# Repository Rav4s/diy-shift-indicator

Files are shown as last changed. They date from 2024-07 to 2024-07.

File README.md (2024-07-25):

# K-Line (ISO9141) Shift Indicator
A DIY shift indicator for manual transmission cars like my Mazda MX-5 with a K-Line (ISO9141) OBDII interface. The device uses a series of LEDs that illuminate based on engine speed (RPM) to help the driver know when to shift gears in high-pressure situations. My technical writeup for this project, which includes rationale, insight into my design/development process, and future plans can be found [here](https://drive.google.com/file/d/1h4sEP5iF2pkmRt12-wAFUMqSv9QvsOz3/view). Additionally, here are videos of the [startup sequence](https://drive.google.com/file/d/1yGfBQFOaLi5DHMowFaSR_DUKHt-pPL1-/view?usp=sharing) and the [device in action](https://drive.google.com/file/d/1uUzjxnDBYHzpRwuf0LmYo11RxKfqu849/view?usp=sharing).  

## Features
- Displays engine RPM using a set of seven LEDs
- Has three distinct LED colors to show progression from low to high RPM (green -> blue -> red)
- Begins illuminating LEDs at the lower end of shift range (3.5k) and fully illuminates by the higher end (6k), with equal steps in between
- Mounts to the dashboard without significantly obstructing the driver's view of the road
- Doesn't require any modifications to wiring/electronics of the car (plug-and-play)

## Files
The file structure of this repository is as follows: 

```
diy-shift-indicator
│   K-Line (ISO 9141) Shift Indicator Writeup.pdf -- technical writeup on design/development process and future plans
│   LICENSE
│   README.md
│
├───Code -- all Arduino code
│   ├───arduino_obd_reader_display -- code for polling and displaying RPM using LED series
│   │       arduino_obd_reader_display.ino -- handles initialization/communication over LIN bus
│   │       LED_driver.ino -- defines functions to drive and reset LEDs, provides displayRPM functionality
│   │
│   ├───LED_test -- tester sketch to ensure LED series is working
│   │       LED_test.ino
│   │
│   └───modified_iso9141_library -- modified version of the OBD9141 Arduino library used in display program
│           OBD9141.cpp
│           OBD9141.h
│
├───Debug -- Saleae logic analyzer capture files, useful for debugging initialization/connection with ECU
│       First_Success_TX_and_KLINE_Logic.sal
│       RX_Logic.sal
│       TX_and_KLINE_Logic.sal
│       TX_Logic.sal
│
└───Design -- CAD/design files from the prototyping process
    │   Device BOM.xlsx -- full bill of materials for the final product (PCB, boards, wiring, enclosure, etc.)
    │
    ├───Electronics -- breadboard, schematic, and PCB design files
    │   ├───Fritzing (Breadboard)
    │   │       Prototype Design.fzz -- breadboard setup designed for original prototype/testbed
    │   │       SN65HVDA195 IC Part.fzz -- custom Fritzing part designed for LIN transceiver IC
    │   │
    │   └───KiCad (PCB)
    │       └───Shift_Indicator_PCB
    │           │   freerouting.dsn
    │           │   Shift_Indicator_PCB.kicad_pcb -- PCB design for final product, can be exported to Gerbers for fabrication
    │           │   Shift_Indicator_PCB.kicad_pcb.zip
    │           │   Shift_Indicator_PCB.kicad_prl
    │           │   Shift_Indicator_PCB.kicad_pro
    │           │   Shift_Indicator_PCB.kicad_sch -- schematic defining all electrical connections for PCB
    │           │   Shift_Indicator_PCB.net -- netlist used to transfer schematic data to PCB design
    │           │   Shift_Indicator_PCB_BOM.csv -- bill of materials for PCB
    │
    └───Mechanics -- enclosure/lid design files
            Enclosure.3mf -- Bambu slicer file for 3D printing enclosure and lid
            Enclosure.stl -- CAD design for device enclosure, can be mounted to car dashboard 
            Lid.stl -- CAD design for lid for the enclosure
```

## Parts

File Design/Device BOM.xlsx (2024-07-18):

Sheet: Full Device BOM
Part Name | Part Number | Cost/Unit | Quantity | Total Cost
C2 (220pF Capacitor) | 0805B221K500BD | $0.04 | 1 | $0.04
C1 (100nF Capacitor) | 0805B104K101CC | $0.06 | 1 | $0.06
R3,R4,R5,R6,R7,R8,R9 (220Ω Resistor) | CRGCQ0805F220R | $0.10 | 7 | $0.70
R1 (1kΩ Resistor) | RC0805FR-071KL | $0.10 | 1 | $0.10
R2 (4.6kΩ Resistor) | ERJ-6ENF4991V | $0.11 | 1 | $0.11
D1,D2 (Rectifier Diode) | 1N4007-T | $0.17 | 2 | $0.34
J1 (11 Position Female Connector Header) | PPTC111LFBN-RC | $0.73 | 1 | $0.73
J2, J3, J4 (1 Position Male Connector Header) | PH1-01-UA | $0.10 | 3 | $0.30
F1 (Fuse Holder) | 0PTF0078P | $0.51 | 1 | $0.51
200mA Fuse | 0235.200HXP | $1.03 | 1 | $1.03
D3, D4, D5 (Green LED) | LTL-709L | $0.37 | 3 | $1.11
J13 (3 Position Female Connector Header) | PPPC031LFBN-RC | $0.38 | 1 | $0.38
D8, D9 (Red LED) | LTL-709E | $0.41 | 2 | $0.82
D6, D7 (Yellow LED) | LTL-709Y | $0.29 | 2 | $0.58
SN65HVDA195 (LIN Bus Transceiver) | SN65HVDA195QDRQ1 | $1.74 | 1 | $1.74
Arduino Uno | A000066 | $27.60 | 1 | $27.60
12V to 5V Buck Converter | B01NALDSJ0 | $9.00 | 1 | $9.00
3D Printer Filament (cost from slicer estimate) | N/A | N/A | N/A | $3.88
OBDII Wire Harness (J1962 Connector) | ‎IKG-40198 | $7.99 | 1 | $7.99

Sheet: Shift_Indicator_PCB_BOM
Reference | Value | Datasheet | Footprint | Qty | DNP | Part Number
C2 | 220pF | ~ | Capacitor_SMD:C_0805_2012Metric_Pad1.18x1.45mm_HandSolder | 1 |  | 0805B221K500BD
C1 | 100nF | ~ | Capacitor_SMD:C_0805_2012Metric_Pad1.18x1.45mm_HandSolder | 1 |  | 0805B104K101CC
R3,R4,R5,R6,R7,R8,R9 | 220Ω | ~ | Resistor_SMD:R_0805_2012Metric_Pad1.20x1.40mm_HandSolder | 7 |  | CRGCQ0805F220R
R1 | 1kΩ | ~ | Resistor_SMD:R_0805_2012Metric_Pad1.20x1.40mm_HandSolder | 1 |  | RC0805FR-071KL
R2 | 4.6kΩ | ~ | Resistor_SMD:R_0805_2012Metric_Pad1.20x1.40mm_HandSolder | 1 |  | ERJ-6ENF4991V
D1,D2 | 1N4007 | http://www.vishay.com/docs/88503/1n4001.pdf | Diode_THT:D_DO-41_SOD81_P10.16mm_Horizontal | 2 |  | 1N4007-T
J1 | Arduino Connector | ~ | Connector_PinSocket_2.54mm:PinSocket_1x11_P2.54mm_Vertical | 1 |  | PPTC111LFBN-RC
J3 | Batt | ~ | Connector_PinHeader_2.54mm:PinHeader_1x01_P2.54mm_Vertical | 1 |  | PH1-01-UA
F1 | Fuse (200mA) | ~ | Fuse:Fuseholder_Cylinder-5x20mm_Stelvio-Kontek_PTF78_Horizontal_Open | 1 |  | F6094-ND & 0235.200HXP
J2 | GND | ~ | Connector_PinHeader_2.54mm:PinHeader_1x01_P2.54mm_Vertical | 1 |  | PH1-01-UA
D3 | Green LED 1 | ~ | LED_THT:LED_D1.8mm_W3.3mm_H2.4mm | 1 |  | LTL-709L
D4 | Green LED 2 | ~ | LED_THT:LED_D1.8mm_W3.3mm_H2.4mm | 1 |  | LTL-709L
D5 | Green LED 3 | ~ | LED_THT:LED_D1.8mm_W3.3mm_H2.4mm | 1 |  | LTL-709L
J4 | LIN | ~ | Connector_PinHeader_2.54mm:PinHeader_1x01_P2.54mm_Vertical | 1 |  | PH1-01-UA
J13 | OBDII Connector | ~ | Connector_PinSocket_2.54mm:PinSocket_1x03_P2.54mm_Vertical | 1 |  | PPPC031LFBN-RC
D8 | Red LED 1 | ~ | LED_THT:LED_D1.8mm_W3.3mm_H2.4mm | 1 |  | LTL-709E
D9 | Red LED 2 | ~ | LED_THT:LED_D1.8mm_W3.3mm_H2.4mm | 1 |  | LTL-709E
D6 | Yellow LED 1 | ~ | LED_THT:LED_D1.8mm_W3.3mm_H2.4mm | 1 |  | LTL-709Y
D7 | Yellow LED 2 | ~ | LED_THT:LED_D1.8mm_W3.3mm_H2.4mm | 1 |  | LTL-709Y
SN65HVDA195 | ~ |  | Package_SO:SOIC-8_3.9x4.9mm_P1.27mm | 1 |  | SN65HVDA195QDRQ1

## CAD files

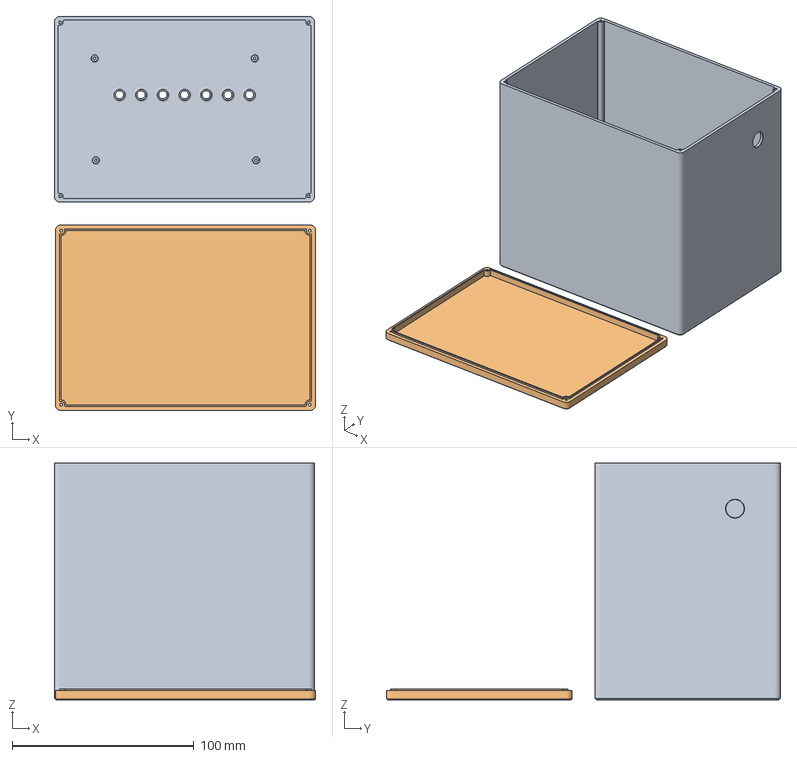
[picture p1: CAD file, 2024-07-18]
Design/Mechanics/Enclosure.3mf
143.5 x 216.5 x 130.0 mm
Enclosure.stl
Lid.stl

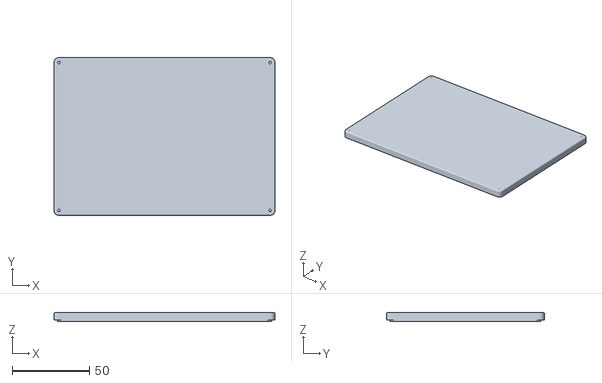
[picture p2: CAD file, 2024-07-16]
Design/Mechanics/Lid.stl
143.0 x 102.0 x 6.00

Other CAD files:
Design/Mechanics/Enclosure.stl

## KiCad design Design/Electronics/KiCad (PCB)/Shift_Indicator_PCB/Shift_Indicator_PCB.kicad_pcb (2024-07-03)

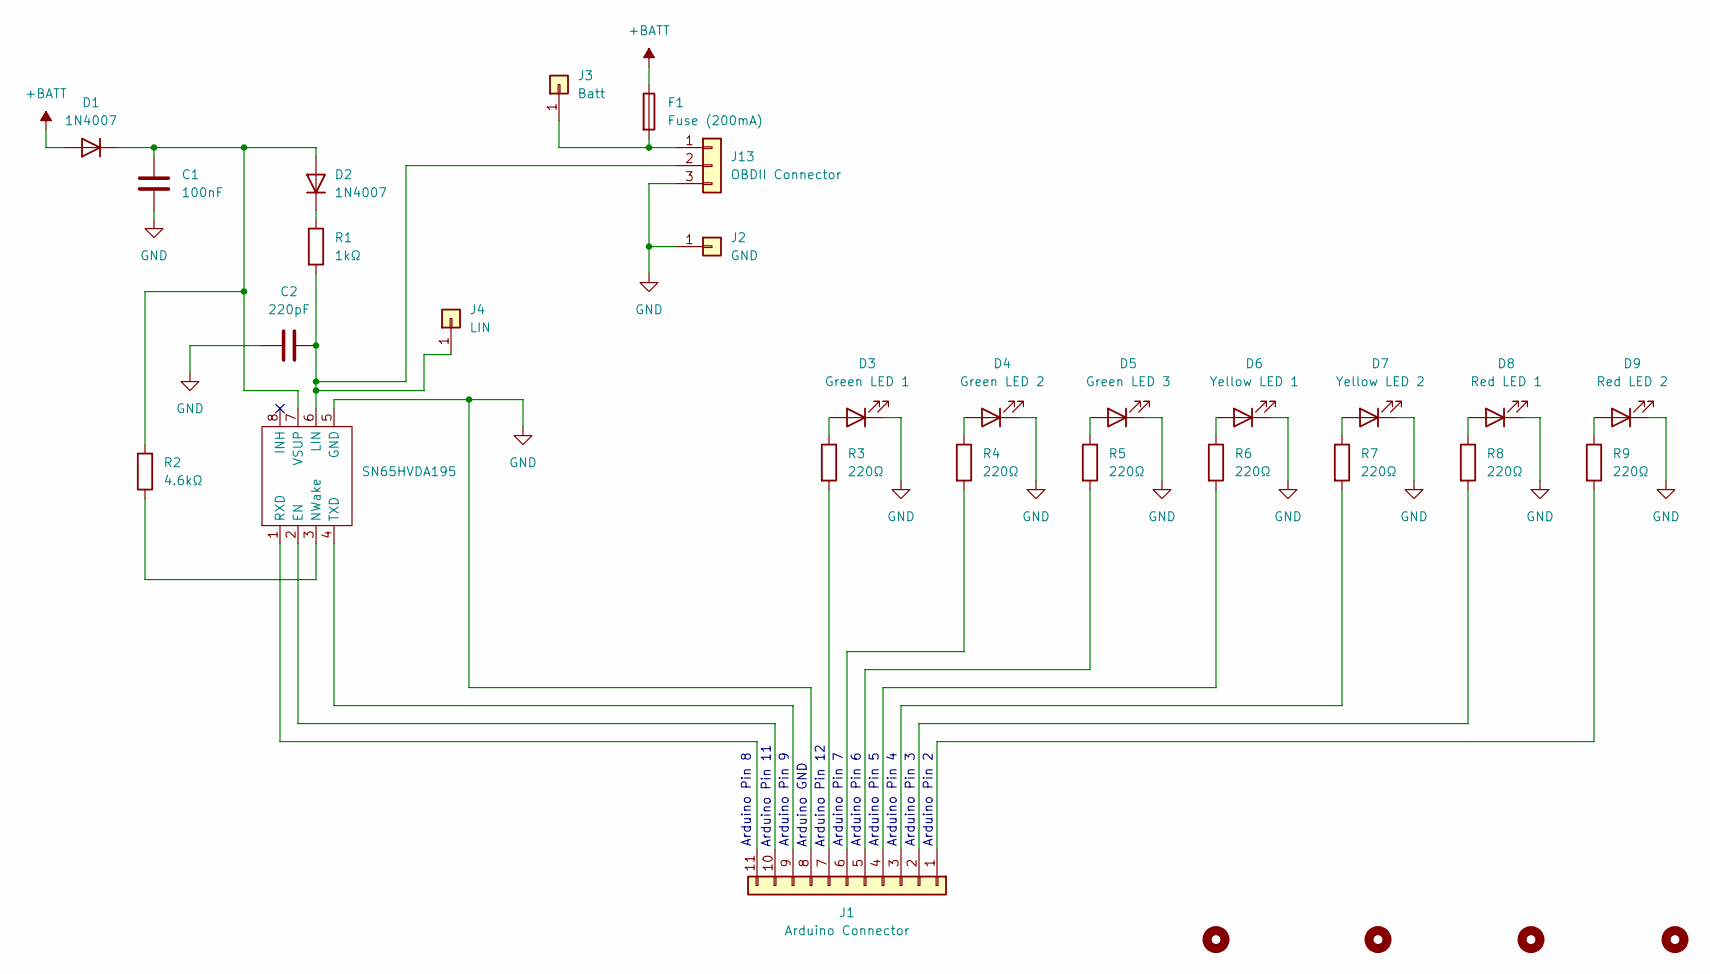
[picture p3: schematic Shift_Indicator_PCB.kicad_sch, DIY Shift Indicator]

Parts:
C1: 100nF; C_0805_2012Metric_Pad1.18x1.45mm_HandSolder
C2: 220pF; C_0805_2012Metric_Pad1.18x1.45mm_HandSolder
D1, D2: 1N4007; D_DO-41_SOD81_P10.16mm_Horizontal
D3: Green LED 1; LED_D1.8mm_W3.3mm_H2.4mm
D4: Green LED 2; LED_D1.8mm_W3.3mm_H2.4mm
D5: Green LED 3; LED_D1.8mm_W3.3mm_H2.4mm
D6: Yellow LED 1; LED_D1.8mm_W3.3mm_H2.4mm
D7: Yellow LED 2; LED_D1.8mm_W3.3mm_H2.4mm
D8: Red LED 1; LED_D1.8mm_W3.3mm_H2.4mm
D9: Red LED 2; LED_D1.8mm_W3.3mm_H2.4mm
F1: Fuse (200mA); Fuseholder_Cylinder-5x20mm_Stelvio-Kontek_PTF78_Horizontal_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
H1, H2, H3, H4: MountingHole; MountingHole_3.2mm_M3_Pad
J1: Arduino Connector; PinSocket_1x11_P2.54mm_Vertical
J2: GND; PinHeader_1x01_P2.54mm_Vertical
J3: Batt; PinHeader_1x01_P2.54mm_Vertical
J4: LIN; PinHeader_1x01_P2.54mm_Vertical
J13: OBDII Connector; PinSocket_1x03_P2.54mm_Vertical
R1: 1kΩ; R_0805_2012Metric_Pad1.20x1.40mm_HandSolder
R2: 4.6kΩ; R_0805_2012Metric_Pad1.20x1.40mm_HandSolder
R3, R4, R5, R6, R7, R8, R9: 220Ω; R_0805_2012Metric_Pad1.20x1.40mm_HandSolder
SN65HVDA195: SOIC-8_3.9x4.9mm_P1.27mm

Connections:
+BATT: D1.2 (A), F1.1
GND: C1.2, C2.1, D3.1 (K), D4.1 (K), D5.1 (K), D6.1 (K), D7.1 (K), D8.1 (K), D9.1 (K), J1.8, J2.1, J13.3, SN65HVDA195.5 (GND)
unnamed: C1.1, D1.1 (K), D2.2 (A), R2.2, SN65HVDA195.7 (VSUP)
unnamed: D2.1 (K), R1.1
unnamed: D3.2 (A), R3.1
unnamed: D4.2 (A), R4.1
unnamed: D5.2 (A), R5.1
unnamed: D6.2 (A), R6.1
unnamed: D7.2 (A), R7.1
unnamed: D8.2 (A), R8.1
unnamed: D9.2 (A), R9.1
unnamed: J1.1, R9.2
unnamed: J1.2, R8.2
unnamed: J1.3, R7.2
unnamed: J1.4, R6.2
unnamed: J1.5, R5.2
unnamed: J1.6, R4.2
unnamed: J1.7, R3.2
unnamed: J1.9, SN65HVDA195.4 (TXD)
unnamed: J1.10, SN65HVDA195.2 (EN)
unnamed: J1.11, SN65HVDA195.1 (RXD)
unnamed: F1.2, J3.1, J13.1
unnamed: C2.2, J4.1, J13.2, R1.2, SN65HVDA195.6 (LIN)
unnamed: R2.1, SN65HVDA195.3 (NWake)

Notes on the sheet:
Arduino Pin 12
Arduino Pin 8
Arduino Pin 2
Arduino GND
Arduino Pin 11
Arduino Pin 3
Arduino Pin 4
Arduino Pin 6
Arduino Pin 5
Arduino Pin 7
Arduino Pin 9

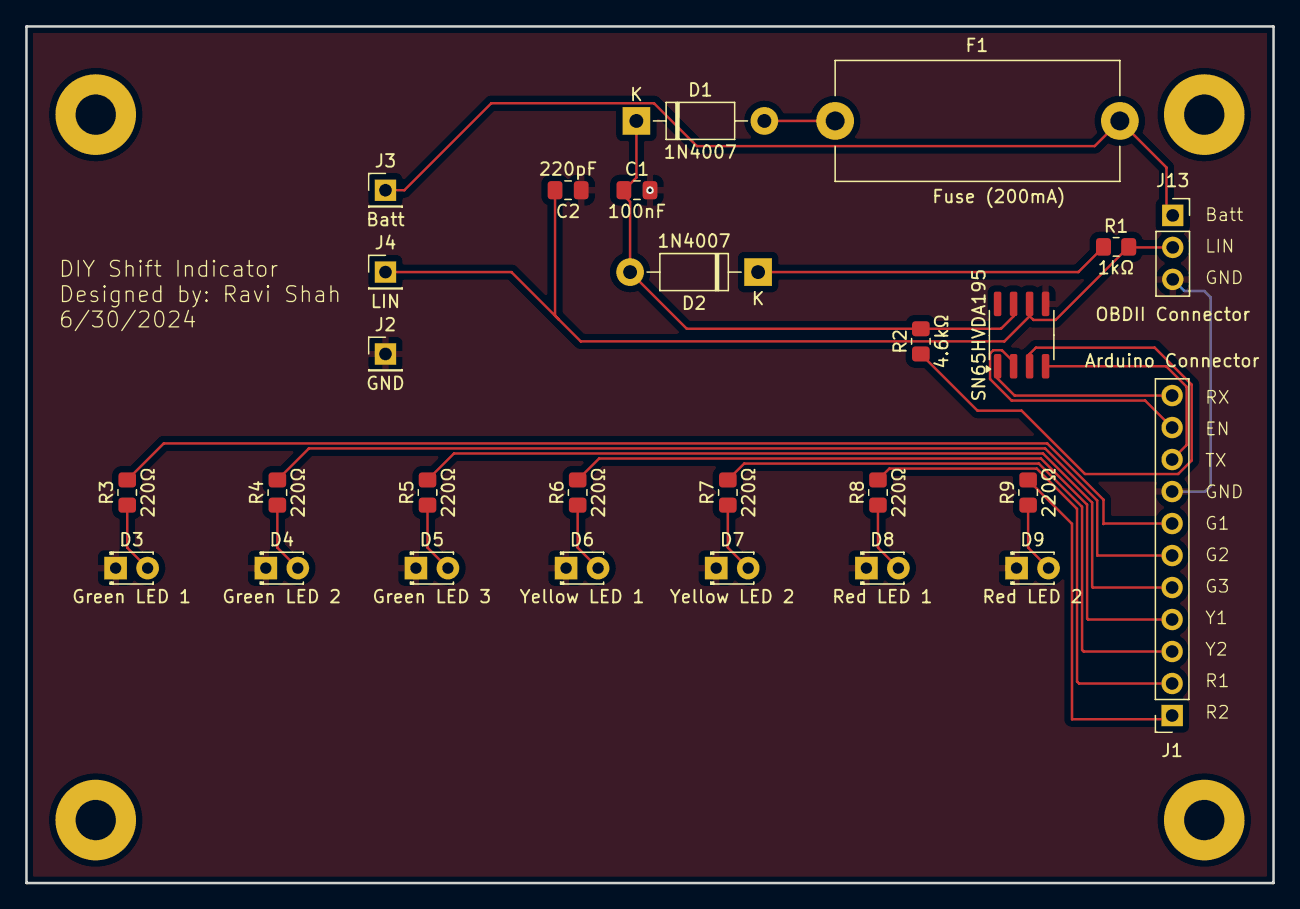
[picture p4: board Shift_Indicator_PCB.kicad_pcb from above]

Board: 2 copper layers, 99.0 x 68.0 mm, 31 parts (0 on the bottom side), 24 nets.

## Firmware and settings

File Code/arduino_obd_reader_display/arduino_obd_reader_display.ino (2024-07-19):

// IMPORTANT: Changed delay in ISO9141 library to match logic analyzer findings on K-Line - specifically, changed initialization serial timeout to 150ms

#include "Arduino.h"
// Be sure that the AltSoftSerial library is available, download it from http://www.pjrc.com/teensy/td_libs_AltSoftSerial.html"
#include "AltSoftSerial.h"


#include "OBD9141.h"

// Pin definitions for TI LIN bus transceiver
#define RX_PIN 8   // connect to transceiver Rx
#define TX_PIN 9   // connect to transceiver Tx
#define EN_PIN 11  //  pin will be set high (connect to EN pin of SN65HVDA100)

// Pin definitions for 7 LED display
#define GREEN_ONE 13
#define GREEN_TWO 7
#define GREEN_THREE 6
#define YELLOW_ONE 5
#define YELLOW_TWO 4
#define RED_ONE 3
#define RED_TWO 2

AltSoftSerial altSerial;

OBD9141 obd;


void setup() {

  // Set all LED pins as outputs
  pinMode(GREEN_ONE, OUTPUT);
  pinMode(GREEN_TWO, OUTPUT);
  pinMode(GREEN_THREE, OUTPUT);
  pinMode(YELLOW_ONE, OUTPUT);
  pinMode(YELLOW_TWO, OUTPUT);
  pinMode(RED_ONE, OUTPUT);
  pinMode(RED_TWO, OUTPUT);

  Serial.begin(9600);
  delay(2000);
  pinMode(EN_PIN, OUTPUT);
  digitalWrite(EN_PIN, HIGH);  // enable the transceiver IC.

  obd.begin(altSerial, RX_PIN, TX_PIN);
}

void loop() {
  Serial.println("Looping");

  bool init_success = obd.init(); // Attempt to initialize connection with ECU
  Serial.print("init_success:");
  Serial.println(init_success);

  if (init_success) {

    startup(); // Display startup sequence on LEDs

    bool res;
    int RPM;
    while (1) {

      res = obd.getCurrentPID(0x0C, 2); // request current RPM value
      if (res) {
        Serial.print("Result 0x0C (RPM): ");
        RPM = (obd.readUint16() / 4); // convert to usable value
        Serial.println(RPM);
        displayRPM(RPM); // display on LED series
      }

      Serial.println();

      delay(100); // wait 100ms to loop
    }
  }
  delay(3000);
}

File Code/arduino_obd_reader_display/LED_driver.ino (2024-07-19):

// LED Driver file contains functions to display certain values using the 7 LEDs on the device

// Startup sequence runs when device is connected and initializes a connection with the ECU
// Turn on all lights starting from left (green) to right (red) and flash three times to show successful startup
void startup() {
  digitalWrite(GREEN_ONE, HIGH);
  delay(250);
  digitalWrite(GREEN_TWO, HIGH);
  delay(250);
  digitalWrite(GREEN_THREE, HIGH);
  delay(250);
  digitalWrite(YELLOW_ONE, HIGH);
  delay(250);
  digitalWrite(YELLOW_TWO, HIGH);
  delay(250);
  digitalWrite(RED_ONE, HIGH);
  delay(250);
  digitalWrite(RED_TWO, HIGH);
  delay(250);
  digitalWrite(GREEN_ONE, LOW);
  digitalWrite(GREEN_TWO, LOW);
  digitalWrite(GREEN_THREE, LOW);
  digitalWrite(YELLOW_ONE, LOW);
  digitalWrite(YELLOW_TWO, LOW);
  digitalWrite(RED_ONE, LOW);
  digitalWrite(RED_TWO, LOW);
  delay(500);
  digitalWrite(GREEN_ONE, HIGH);
  digitalWrite(GREEN_TWO, HIGH);
  digitalWrite(GREEN_THREE, HIGH);
  digitalWrite(YELLOW_ONE, HIGH);
  digitalWrite(YELLOW_TWO, HIGH);
  digitalWrite(RED_ONE, HIGH);
  digitalWrite(RED_TWO, HIGH);
  delay(500);
  digitalWrite(GREEN_ONE, LOW);
  digitalWrite(GREEN_TWO, LOW);
  digitalWrite(GREEN_THREE, LOW);
  digitalWrite(YELLOW_ONE, LOW);
  digitalWrite(YELLOW_TWO, LOW);
  digitalWrite(RED_ONE, LOW);
  digitalWrite(RED_TWO, LOW);
  delay(500);
  digitalWrite(GREEN_ONE, HIGH);
  digitalWrite(GREEN_TWO, HIGH);
  digitalWrite(GREEN_THREE, HIGH);
  digitalWrite(YELLOW_ONE, HIGH);
  digitalWrite(YELLOW_TWO, HIGH);
  digitalWrite(RED_ONE, HIGH);
  digitalWrite(RED_TWO, HIGH);
  delay(500);
  digitalWrite(GREEN_ONE, LOW);
  digitalWrite(GREEN_TWO, LOW);
  digitalWrite(GREEN_THREE, LOW);
  digitalWrite(YELLOW_ONE, LOW);
  digitalWrite(YELLOW_TWO, LOW);
  digitalWrite(RED_ONE, LOW);
  digitalWrite(RED_TWO, LOW);
  delay(500);
  digitalWrite(GREEN_ONE, HIGH);
  digitalWrite(GREEN_TWO, HIGH);
  digitalWrite(GREEN_THREE, HIGH);
  digitalWrite(YELLOW_ONE, HIGH);
  digitalWrite(YELLOW_TWO, HIGH);
  digitalWrite(RED_ONE, HIGH);
  digitalWrite(RED_TWO, HIGH);
  delay(500);
  digitalWrite(GREEN_ONE, LOW);
  digitalWrite(GREEN_TWO, LOW);
  digitalWrite(GREEN_THREE, LOW);
  digitalWrite(YELLOW_ONE, LOW);
  digitalWrite(YELLOW_TWO, LOW);
  digitalWrite(RED_ONE, LOW);
  digitalWrite(RED_TWO, LOW);
}

// Functions one to seven describe behavior for the LED display when one through seven lights are illuminated
void one() {
  digitalWrite(GREEN_ONE, HIGH);
}

void two() {
  digitalWrite(GREEN_ONE, HIGH);
  digitalWrite(GREEN_TWO, HIGH);
}

void three() {
  digitalWrite(GREEN_ONE, HIGH);
  digitalWrite(GREEN_TWO, HIGH);
  digitalWrite(GREEN_THREE, HIGH);
}

void four() {
  digitalWrite(GREEN_ONE, HIGH);
  digitalWrite(GREEN_TWO, HIGH);
  digitalWrite(GREEN_THREE, HIGH);
  digitalWrite(YELLOW_ONE, HIGH);
}

void five() {
  digitalWrite(GREEN_ONE, HIGH);
  digitalWrite(GREEN_TWO, HIGH);
  digitalWrite(GREEN_THREE, HIGH);
  digitalWrite(YELLOW_ONE, HIGH);
  digitalWrite(YELLOW_TWO, HIGH);
}

void six() {
  digitalWrite(GREEN_ONE, HIGH);
  digitalWrite(GREEN_TWO, HIGH);
  digitalWrite(GREEN_THREE, HIGH);
  digitalWrite(YELLOW_ONE, HIGH);
  digitalWrite(YELLOW_TWO, HIGH);
  digitalWrite(RED_ONE, HIGH);
}

void seven() {
  digitalWrite(GREEN_ONE, HIGH);
  digitalWrite(GREEN_TWO, HIGH);
  digitalWrite(GREEN_THREE, HIGH);
  digitalWrite(YELLOW_ONE, HIGH);
  digitalWrite(YELLOW_TWO, HIGH);
  digitalWrite(RED_ONE, HIGH);
  digitalWrite(RED_TWO, HIGH);
}

// Turn off all LEDs
void reset() {
  digitalWrite(GREEN_ONE, LOW);
  digitalWrite(GREEN_TWO, LOW);
  digitalWrite(GREEN_THREE, LOW);
  digitalWrite(YELLOW_ONE, LOW);
  digitalWrite(YELLOW_TWO, LOW);
  digitalWrite(RED_ONE, LOW);
  digitalWrite(RED_TWO, LOW);
}

// Illuminate a certain number of LEDs based on the input RPM value
void displayRPM(int RPM) {

  reset();

  // Use RPM value to determine which display option to use
  if (RPM <= 3000) {
    reset();
  } else if (RPM <= 3500) {
    one();
  } else if (RPM <= 3930) {
    two();
  } else if (RPM <= 4360) {
    three();
  } else if (RPM <= 4790) {
    four();
  } else if (RPM <= 5220) {
    five();
  } else if (RPM <= 5650) {
    six();
  } else {
    seven();
  }
}

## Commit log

2024-05-18 Added initial prototype design file
    [Prototype Design.fzz]
2024-05-18 Add k-line and OBDII connector
    [Prototype Design.fzz]
2024-05-22 Added prototype connections for buck converter
    [Prototype Design.fzz]
2024-06-04 Update proto
    [Prototype Design.fzz]
2024-06-04 create custom part for SN65HVDA195 IC
    [SN65HVDA195 IC Part.fzz]
2024-06-04 update circuit designs with IC implementation
    [Prototype Design.fzz, SN65HVDA195 IC Part.fzz]
2024-06-13 update pins to match board
2024-06-13 Added LED test code
2024-06-24 refresh files
    [Prototype Design.fzz]
2024-06-27 change pins to correct ones for altsoftserial
    [arduino_obd_reader_display.ino]
2024-06-28 reorganize and add KiCad project
    [Prototype Design.fzz, SN65HVDA195 IC Part.fzz, Shift_Indicator_PCB.kicad_pcb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]
2024-06-29 add file shell for LED driver
2024-06-30 first half of schematic
    [Shift_Indicator_PCB.kicad_sch]
2024-07-01 add gitignore for kicad
2024-07-01 add LED display on schematic
    [Shift_Indicator_PCB.kicad_pcb, Shift_Indicator_PCB.kicad_sch]
2024-07-01 schematic: added proper connectors for OBDII and Arduino
    [Shift_Indicator_PCB.kicad_sch]
2024-07-02 added first iteration of PCB
    [Shift_Indicator_PCB.kicad_pcb, Shift_Indicator_PCB.kicad_sch, freerouting.dsn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]
2024-07-03 fix PCB for approval + netlist/BOM
    [Shift_Indicator_PCB.kicad_pcb, Shift_Indicator_PCB.kicad_sch, Shift_Indicator_PCB_BOM.csv]
2024-07-04 add all DigiKey part numbers to BOM
    [Shift_Indicator_PCB.kicad_sch, Shift_Indicator_PCB_BOM.csv]
2024-07-14 fix to working pin
    [arduino_obd_reader_display.ino]
2024-07-15 change pin for testing
2024-07-16 created cad models for enclosure and lid
    [Enclosure.stl, Lid.stl]
2024-07-16 chamfer front edges on enclosure
    [Enclosure.stl]
2024-07-18 add bambu slicer file
    [Enclosure.3mf]
2024-07-18 add full device BOM
    [Device BOM.xlsx, Shift_Indicator_PCB_BOM.csv]
2024-07-24 Add links to videos of device
